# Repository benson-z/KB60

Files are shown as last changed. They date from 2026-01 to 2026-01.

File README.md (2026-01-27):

# KB60

60% low-profile keyboard



## Features

- 2-layer PCB
- Gateron KS33 Hot-swap Sockets
- USB and Bluetooth Connectivity
- ZMK Studio configurable keymap

## BOM

| Item | Qty |
| --- | --- |
| [nRF58240 Pro Micro](https://a.co/d/fQjZlp4) | 1 |
| [Gateron Low Profile Plate Mounted Stabilizers (2u)](https://www.gateron.com/products/gateron-low-profile-plate-mounted-stabilizer?VariantsId=10477) | 3 |
| [Gateron Low Profile Plate Mounted Stabilizer (6.25u)](https://www.gateron.com/products/gateron-low-profile-plate-mounted-stabilizer?VariantsId=10478) | 1 |
| [Gateron Low Profile Hot-swap PCB 2.0 Socket](https://www.gateron.com/products/gateron-low-profile-switch-hot-swap-pcb-socket?VariantsId=10233) | 64  |
| [NuPhy Aloe Low-profile Switches](https://nuphy.com/collections/switches/products/nuphy-aloe-l37-low-profile-switches) | 64  |
| [Nuphy Shiokaze nSA Profile Keycaps](https://nuphy.com/collections/keycaps/products/shiokaze-nsa-dye-sub-pbt-keycaps?_pos=15&_fid=43f083136&_ss=c) | 1 |
| [3.7V 553454 LiPo Battery](https://a.co/d/7SXFvsk) | 1 |
| M3x10mm Button Head Screw | 2 |
| M3x6mm Button Head Screw | 3 |
| SSSS811101 | 1 |
| 1N4148W | 64  |
| M20-8771346 | 2 |
| S2B-PH-SM4-TB | 1 |
| Case (STEP in Releases tab) | 1 |

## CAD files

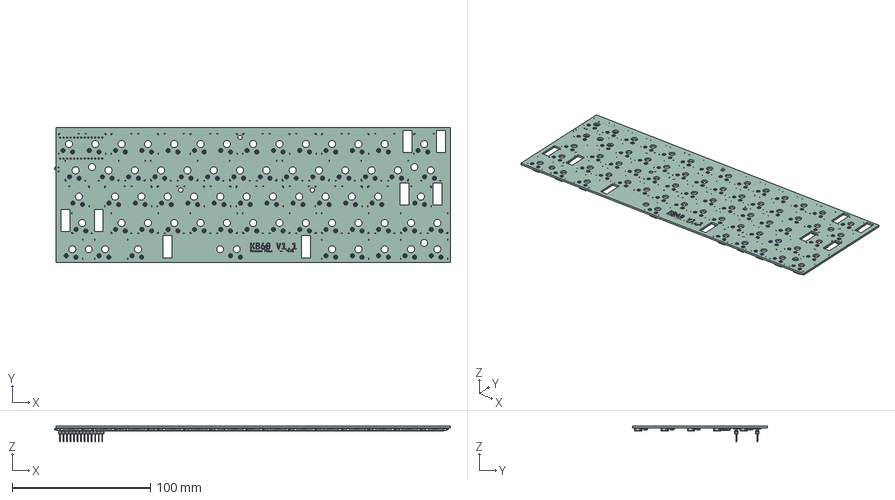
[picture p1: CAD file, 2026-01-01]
pcb/kb.step
286.7 x 97.6 x 11.6 mm
Gateron-KS33-Socket x 64
D_SOD-123 x 64
SSSS811101
kb_silkscreen x 2
kb_PCB

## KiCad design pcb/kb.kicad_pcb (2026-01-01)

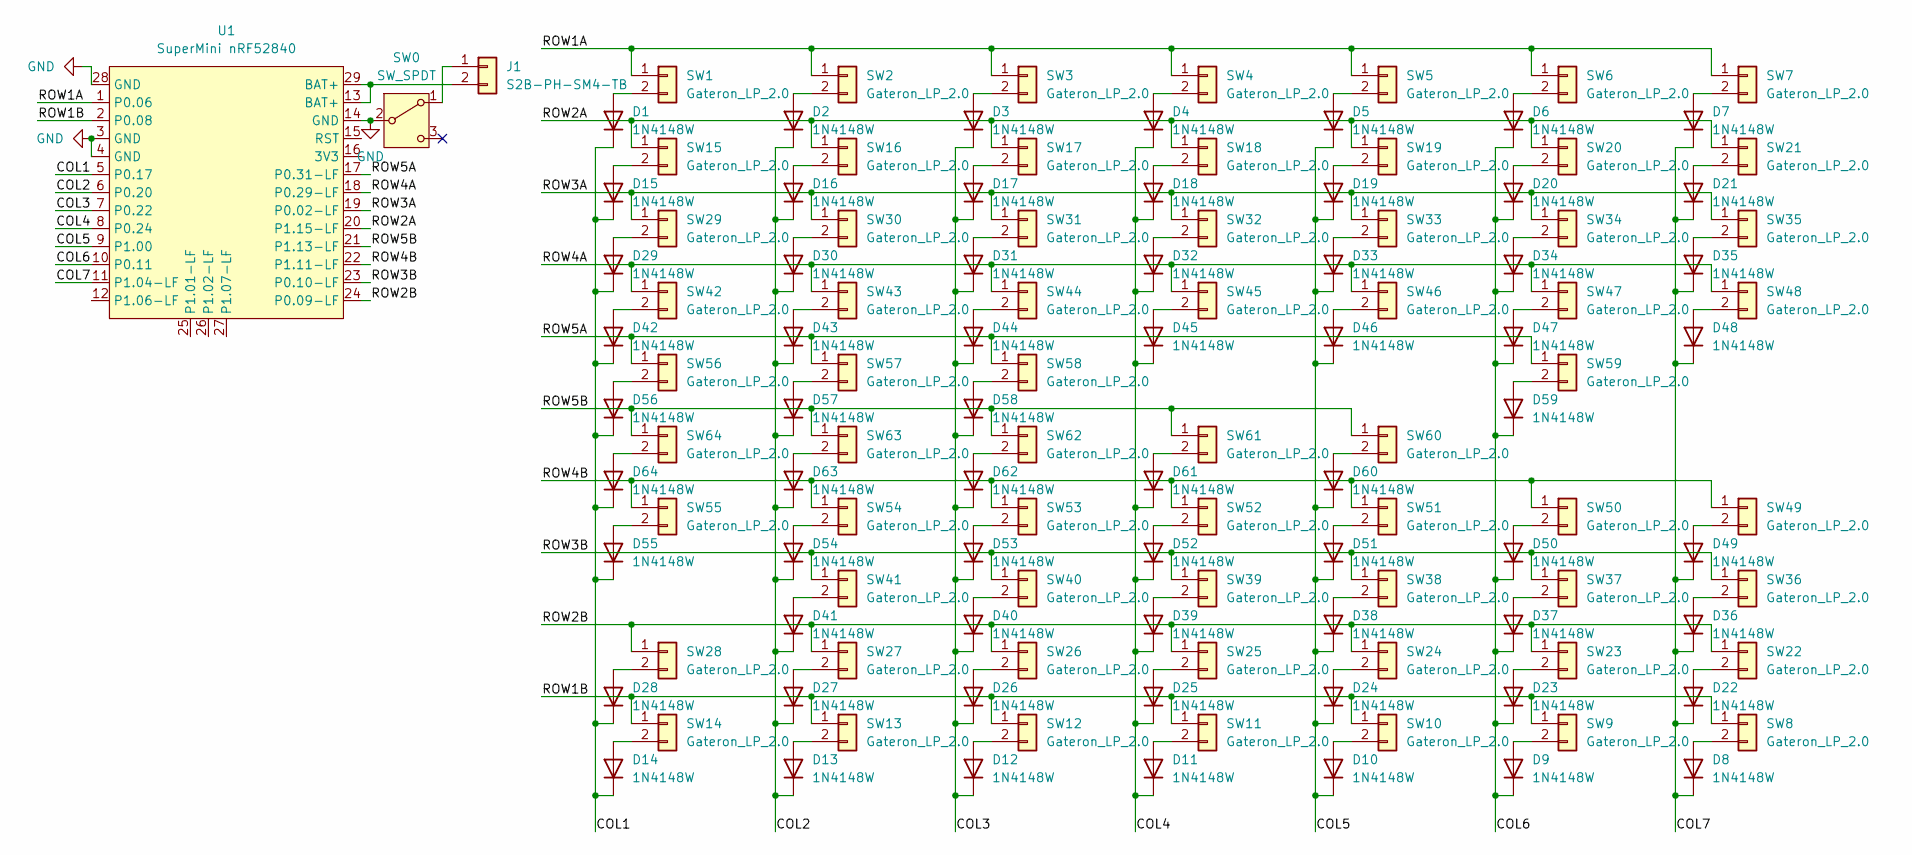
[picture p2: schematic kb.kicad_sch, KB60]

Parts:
D1, D2, D3, D4, D5, D6, D7, D8, D9, D10, D11, D12, D13, D14, D15, D16, D17, D18, D19, D20, D21, D22, D23, D24, D25, D26, D27, D28, D29, D30, D31, D32, D33, D34, D35, D36, D37, D38, D39, D40, D41, D42, D43, D44, D45, D46, D47, D48, D49, D50, D51, D52, D53, D54, D55, D56, D57, D58, D59, D60, D61, D62, D63, D64: 1N4148W; D_SOD-123
J1: S2B-PH-SM4-TB; JST_PH_S2B-PH-SM4-TB_1x02-1MP_P2.00mm_Horizontal
SW0: SW_SPDT; SW_SSSS811101
SW1, SW2, SW3, SW4, SW5, SW6, SW7, SW8, SW9, SW10, SW11, SW12, SW13, SW14, SW15, SW16, SW17, SW18, SW19, SW20, SW21, SW22, SW23, SW24, SW25, SW26, SW27, SW28, SW29, SW30, SW31, SW32, SW33, SW34, SW35, SW36, SW37, SW38, SW39, SW40, SW41, SW42, SW43, SW44, SW45, SW46, SW47, SW48, SW49, SW50, SW51, SW52, SW53, SW54, SW55, SW56, SW57, SW58, SW59, SW60, SW61, SW62, SW63, SW64: Gateron_LP_2.0
U1: SuperMini nRF52840; SuperMini_nRF52840_AH_USBup

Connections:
/COL1: D1.1 (K), D14.1 (K), D15.1 (K), D28.1 (K), D29.1 (K), D42.1 (K), D55.1 (K), D56.1 (K), D64.1 (K), U1.5 (P0.17)
/COL2: D2.1 (K), D13.1 (K), D16.1 (K), D27.1 (K), D30.1 (K), D41.1 (K), D43.1 (K), D54.1 (K), D57.1 (K), D63.1 (K), U1.6 (P0.20)
/COL3: D3.1 (K), D12.1 (K), D17.1 (K), D26.1 (K), D31.1 (K), D40.1 (K), D44.1 (K), D53.1 (K), D58.1 (K), D62.1 (K), U1.7 (P0.22)
/COL4: D4.1 (K), D11.1 (K), D18.1 (K), D25.1 (K), D32.1 (K), D39.1 (K), D45.1 (K), D52.1 (K), D61.1 (K), U1.8 (P0.24)
/COL5: D5.1 (K), D10.1 (K), D19.1 (K), D24.1 (K), D33.1 (K), D38.1 (K), D46.1 (K), D51.1 (K), D60.1 (K), U1.9 (P1.00)
/COL6: D6.1 (K), D9.1 (K), D20.1 (K), D23.1 (K), D34.1 (K), D37.1 (K), D47.1 (K), D50.1 (K), D59.1 (K), U1.10 (P0.11)
/COL7: D7.1 (K), D8.1 (K), D21.1 (K), D22.1 (K), D35.1 (K), D36.1 (K), D48.1 (K), D49.1 (K), U1.11 (P1.04-LF)
/ROW1A: SW1.1, SW2.1, SW3.1, SW4.1, SW5.1, SW6.1, SW7.1, U1.1 (P0.06)
/ROW1B: SW8.1, SW9.1, SW10.1, SW11.1, SW12.1, SW13.1, SW14.1, U1.2 (P0.08)
/ROW2A: SW15.1, SW16.1, SW17.1, SW18.1, SW19.1, SW20.1, SW21.1, U1.20 (P1.15-LF)
/ROW2B: SW22.1, SW23.1, SW24.1, SW25.1, SW26.1, SW27.1, SW28.1, U1.24 (P0.09-LF)
/ROW3A: SW29.1, SW30.1, SW31.1, SW32.1, SW33.1, SW34.1, SW35.1, U1.19 (P0.02-LF)
/ROW3B: SW36.1, SW37.1, SW38.1, SW39.1, SW40.1, SW41.1, U1.23 (P0.10-LF)
/ROW4A: SW42.1, SW43.1, SW44.1, SW45.1, SW46.1, SW47.1, SW48.1, U1.18 (P0.29-LF)
/ROW4B: SW49.1, SW50.1, SW51.1, SW52.1, SW53.1, SW54.1, SW55.1, U1.22 (P1.11-LF)
/ROW5A: SW56.1, SW57.1, SW58.1, SW59.1, U1.17 (P0.31-LF)
/ROW5B: SW60.1, SW61.1, SW62.1, SW63.1, SW64.1, U1.21 (P1.13-LF)
GND: SW0.2 (B), U1.3 (GND), U1.4 (GND), U1.14 (GND), U1.28 (GND)
unnamed: D1.2 (A), SW1.2
unnamed: D2.2 (A), SW2.2
unnamed: D3.2 (A), SW3.2
unnamed: D4.2 (A), SW4.2
unnamed: D5.2 (A), SW5.2
unnamed: D6.2 (A), SW6.2
unnamed: D7.2 (A), SW7.2
unnamed: D8.2 (A), SW8.2
unnamed: D9.2 (A), SW9.2
unnamed: D10.2 (A), SW10.2
unnamed: D11.2 (A), SW11.2
unnamed: D12.2 (A), SW12.2
unnamed: D13.2 (A), SW13.2
unnamed: D14.2 (A), SW14.2
unnamed: D15.2 (A), SW15.2
unnamed: D16.2 (A), SW16.2
unnamed: D17.2 (A), SW17.2
unnamed: D18.2 (A), SW18.2
unnamed: D19.2 (A), SW19.2
unnamed: D20.2 (A), SW20.2
unnamed: D21.2 (A), SW21.2
unnamed: D22.2 (A), SW22.2
unnamed: D23.2 (A), SW23.2
unnamed: D24.2 (A), SW24.2
unnamed: D25.2 (A), SW25.2
unnamed: D26.2 (A), SW26.2
unnamed: D27.2 (A), SW27.2
unnamed: D28.2 (A), SW28.2
unnamed: D29.2 (A), SW29.2
unnamed: D30.2 (A), SW30.2
unnamed: D31.2 (A), SW31.2
unnamed: D32.2 (A), SW32.2
unnamed: D33.2 (A), SW33.2
unnamed: D34.2 (A), SW34.2
unnamed: D35.2 (A), SW35.2
unnamed: D36.2 (A), SW36.2
unnamed: D37.2 (A), SW37.2
unnamed: D38.2 (A), SW38.2
unnamed: D39.2 (A), SW39.2
unnamed: D40.2 (A), SW40.2
unnamed: D41.2 (A), SW41.2
unnamed: D42.2 (A), SW42.2
unnamed: D43.2 (A), SW43.2
unnamed: D44.2 (A), SW44.2
unnamed: D45.2 (A), SW45.2
unnamed: D46.2 (A), SW46.2
unnamed: D47.2 (A), SW47.2
unnamed: D48.2 (A), SW48.2
unnamed: D49.2 (A), SW49.2
unnamed: D50.2 (A), SW50.2
unnamed: D51.2 (A), SW51.2
unnamed: D52.2 (A), SW52.2
unnamed: D53.2 (A), SW53.2
unnamed: D54.2 (A), SW54.2
unnamed: D55.2 (A), SW55.2
unnamed: D56.2 (A), SW56.2
unnamed: D57.2 (A), SW57.2
unnamed: D58.2 (A), SW58.2
unnamed: D59.2 (A), SW59.2
unnamed: D60.2 (A), SW60.2
unnamed: D61.2 (A), SW61.2
unnamed: D62.2 (A), SW62.2
unnamed: D63.2 (A), SW63.2
unnamed: D64.2 (A), SW64.2
unnamed: J1.1, SW0.1 (A)
unnamed: J1.2, U1.13 (BAT+), U1.29 (BAT+)

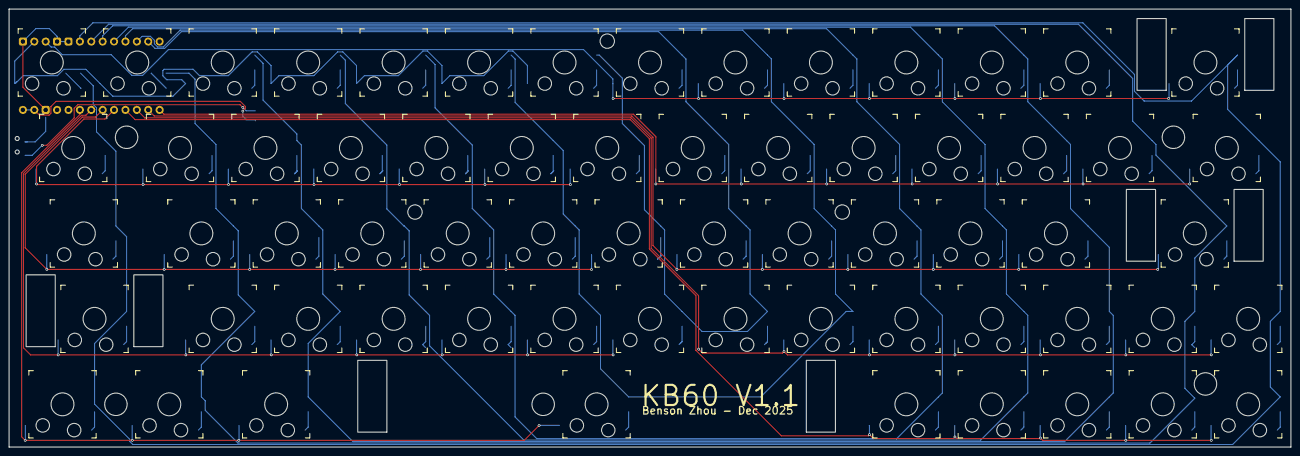
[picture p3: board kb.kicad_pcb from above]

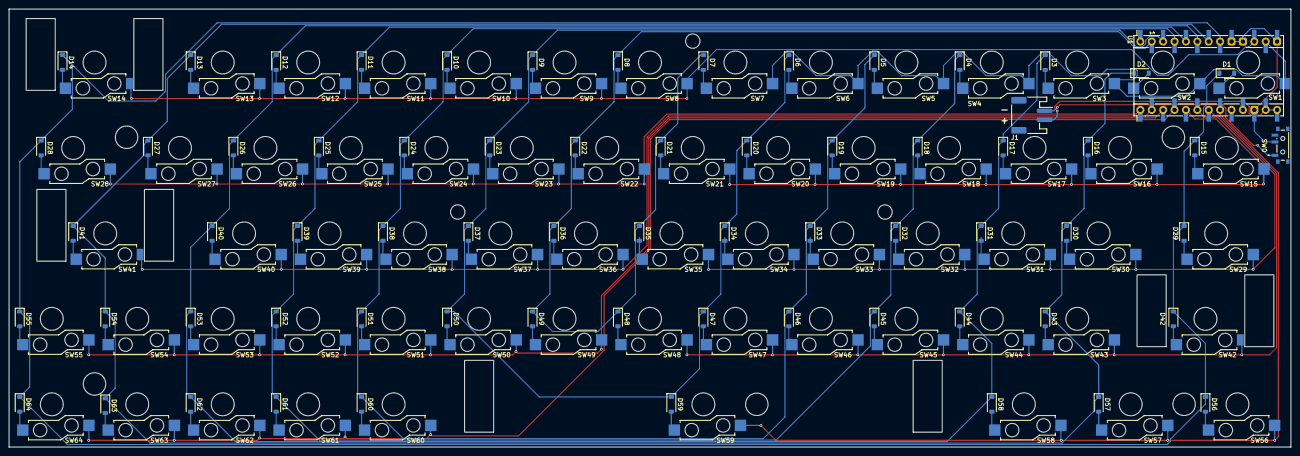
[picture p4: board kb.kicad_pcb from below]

Board: 2 copper layers, 285.8 x 97.6 mm, 131 parts (67 on the bottom side), 84 nets.

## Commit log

2025-12-05 initial layout
    [kb.kicad_pcb, kb.kicad_sch]
2025-12-05 use 1/8u pcb grid
    [kb.kicad_pcb]
2025-12-05 full layout with 19.05mm spacing
    [kb.kicad_pcb]
2025-12-07 placed all components
    [kb.kicad_pcb]
2025-12-07 routed column traces
    [kb.kicad_pcb, kb.kicad_sch]
2025-12-08 routed all traces
    [kb.kicad_pcb, kb.kicad_sch]
2025-12-08 tiny fix
    [kb.kicad_pcb]
2025-12-09 use smd headers to mitigate switch collision
    [kb.kicad_pcb, kb.kicad_sch]
2025-12-09 clean up and add name
    [kb.kicad_pcb]
2025-12-09 add hot swap 3d model
    [kb.kicad_pcb]
2025-12-12 change switch reference
    [kb.kicad_pcb, kb.kicad_sch]
2025-12-12 rewire and fix everything
    [kb.kicad_pcb, kb.kicad_sch]
2025-12-12 shrink 2u hotswap pads
    [kb.kicad_pcb, kb.kicad_sch]
2025-12-13 add battery connector
    [kb.kicad_pcb]
2025-12-13 fix bottom row spacing
    [kb.kicad_pcb]
2025-12-14 compact pcb footprint
    [kb.kicad_pcb]
2025-12-14 fix traces, designators going off pcb
    [kb.kicad_pcb]
2025-12-14 checked all tolerances
    [kb.kicad_pcb, kb.kicad_sch]
2025-12-14 battery switch
    [kb.kicad_pcb, kb.kicad_sch]
2025-12-14 finalize pcb
    [kb.kicad_pcb]
2025-12-27 parallel diodes
    [kb.kicad_sch]
2025-12-28 fix all known issues with v1.0 pcb
    [kb.kicad_pcb, kb.kicad_sch]
2025-12-28 bump pcb version
    [kb.kicad_pcb]
2025-12-28 update footprints + bom
    [kb.kicad_pcb, kb.kicad_sch]
2025-12-28 mounting holes
    [kb.kicad_pcb]
2026-01-01 manufacturing files v1.1
    [kb-B_Cu.gbr, kb-B_Mask.gbr, kb-B_Paste.gbr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]
2026-01-04 battery monitoring
2026-01-12 detect kicad files
